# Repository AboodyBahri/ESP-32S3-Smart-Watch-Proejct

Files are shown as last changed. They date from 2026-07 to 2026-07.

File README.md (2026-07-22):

<div align="center">
  <h1>⌚ Tactical Watch Pro (ESP32-S3)</h1>
  <p><b>Senior Graduation Project | Department of Electronics Engineering — University of Tabuk</b></p>
  <p>An end-to-end, full-stack IoT smartwatch ecosystem engineered around the <b>ESP32-S3 SuperMini</b>. Combines embedded C++ firmware, real-time PPG biometric tracking, a 3D-printed parametric enclosure, and a web-based tele-health analytics dashboard.</p>
</div>

<hr />

<h2>📸 System Gallery</h2>

<div align="center">
  <h3>Hardware Prototype & Analytics Dashboard</h3>
</div>

<table width="100%">
  <tr>
    <td align="center" width="50%">
      <h4>Physical Hardware Prototype</h4>
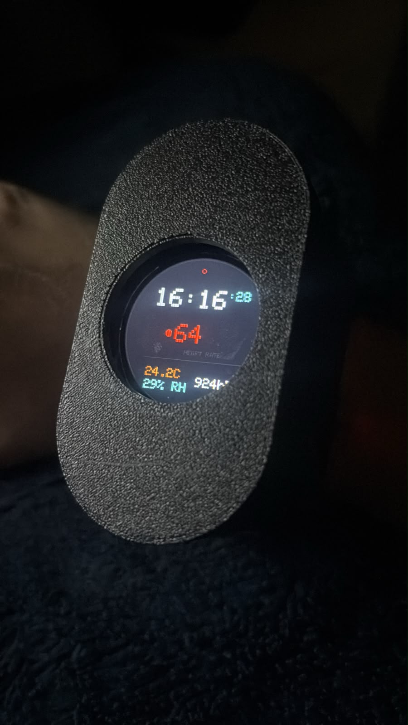
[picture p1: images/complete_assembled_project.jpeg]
Complete Assembled Project
      
    </td>
    <td align="center" width="50%">
      <h4>Web UI Analytics Dashboard</h4>
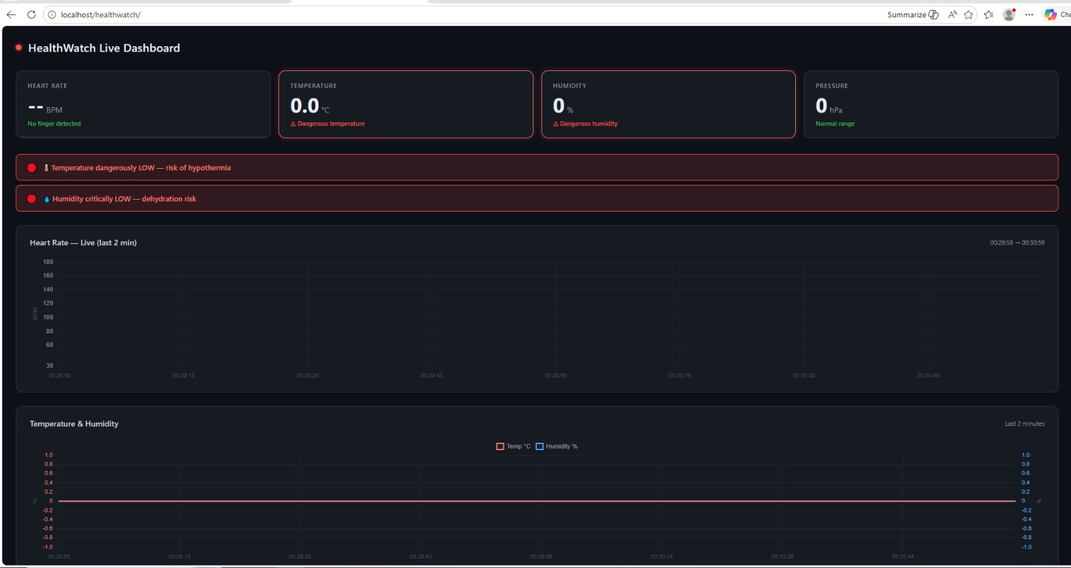
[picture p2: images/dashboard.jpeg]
Watch UI Dashboard
      
    </td>
  </tr>
</table>

<br />

<table width="100%">
  <tr>
    <td align="center" width="50%">
      <h4>Parametric 3D CAD Design</h4>
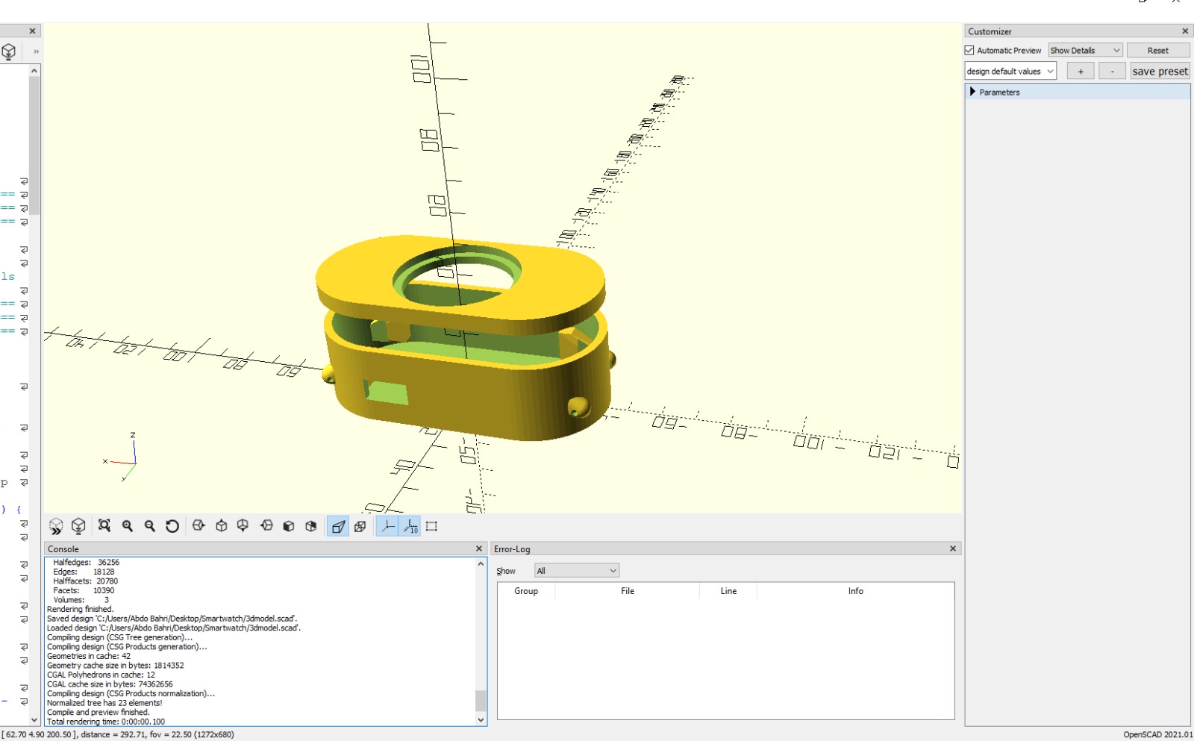
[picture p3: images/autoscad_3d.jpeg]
AutoCAD 3D Model
      
    </td>
    <td align="center" width="50%">
      <h4>Soldered Circuit Assembly</h4>
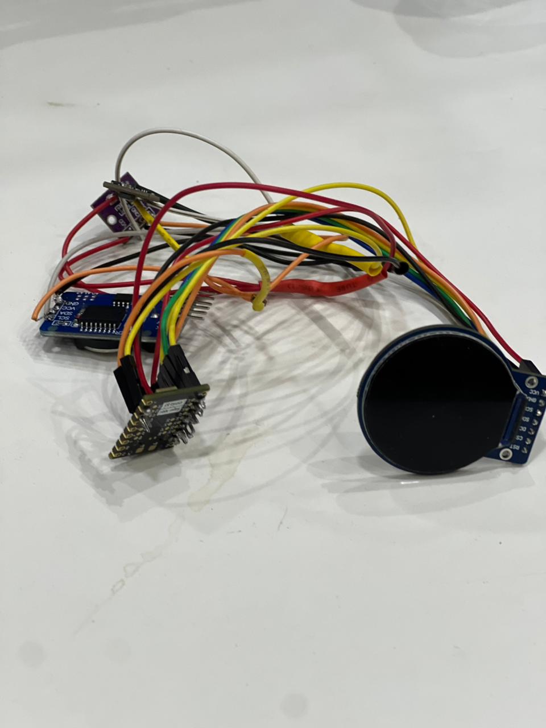
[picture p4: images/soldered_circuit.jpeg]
Soldered Circuit
      
    </td>
  </tr>
  <tr>
    <td align="center" colspan="2">
      <h4>Breadboard Prototype & Signal Testing</h4>
      Test Board Circuit
    </td>
  </tr>
</table>

<hr />

<h2>🛠️ System Architecture & Subsystems</h2>

<table width="100%">
  <thead>
    <tr>
      <th align="left">Subsystem</th>
      <th align="left">Tech / Component</th>
      <th align="left">Engineering Description</th>
    </tr>
  </thead>
  <tbody>
    <tr>
      <td><b>MCU Firmware</b></td>
      <td>ESP32-S3 SuperMini</td>
      <td>Dual-Core Xtensa LX7 @ 240MHz, Wi-Fi 4 &amp; BLE 5.0, Custom C++ Application (<code>esp32s3_code.ino</code>)</td>
    </tr>
    <tr>
      <td><b>Web Dashboard</b></td>
      <td>PHP 8 &amp; JSON Engine</td>
      <td>Hosted tele-health telemetry platform (<code>htdocs/smartwatch/</code>) with RESTful API endpoints for telemetry ingestion</td>
    </tr>
    <tr>
      <td><b>Display UI</b></td>
      <td>GC9A01 LCD (SPI)</td>
      <td>1.28" Round IPS display driven with custom splashscreen header bitmap (<code>splashscreen240.h</code>)</td>
    </tr>
    <tr>
      <td><b>Biometrics</b></td>
      <td>MAX30105 PPG Sensor</td>
      <td>Optical Pulse Oximeter &amp; Heart Rate Sensor operating via I2C interface</td>
    </tr>
    <tr>
      <td><b>Mechanical CAD</b></td>
      <td>OpenSCAD Parametric</td>
      <td>Monolithic 3D capsule enclosure script (<code>smartwatch_full_assembly.scad</code>) with 22mm lug integration</td>
    </tr>
  </tbody>
</table>

<hr />

<h2>🔌 Hardware Pinout Mapping</h2>

<h3>GC9A01 Display Interface (SPI)</h3>
<blockquote>
  <b>Design Note:</b> Display SPI data (MOSI) and reset (RST) lines utilize <b>GPIO 1</b> and <b>GPIO 2</b> to optimize internal physical trace routing away from the USB-C port while minimizing electrical crosstalk with the I2C bus lines.
</blockquote>

<table width="100%">
  <thead>
    <tr>
      <th align="left">GC9A01 Pin</th>
      <th align="left">ESP32-S3 Pin</th>
      <th align="left">Function</th>
      <th align="left">Signal Notes</th>
    </tr>
  </thead>
  <tbody>
    <tr>
      <td><b>SDA (MOSI)</b></td>
      <td><code>GPIO 1</code></td>
      <td>SPI Master Out Slave In</td>
      <td>Custom routed line</td>
    </tr>
    <tr>
      <td><b>RES (RST)</b></td>
      <td><code>GPIO 2</code></td>
      <td>Hardware Reset</td>
      <td>Strapping pin (Boot-safe)</td>
    </tr>
    <tr>
      <td><b>SCL (SCK)</b></td>
      <td><code>GPIO 12</code></td>
      <td>SPI Serial Clock</td>
      <td>Hardware SPI bus</td>
    </tr>
    <tr>
      <td><b>DC</b></td>
      <td><code>GPIO 9</code></td>
      <td>Data / Command Select</td>
      <td>Control line</td>
    </tr>
    <tr>
      <td><b>CS</b></td>
      <td><code>GPIO 13</code></td>
      <td>Chip Select</td>
      <td>Active LOW</td>
    </tr>
    <tr>
      <td><b>VCC / GND</b></td>
      <td><code>3.3V / GND</code></td>
      <td>Power Supply</td>
      <td>Onboard regulated line</td>
    </tr>
  </tbody>
</table>

<br />

<h3>MAX30105 Biometric Sensor (I2C)</h3>

<table width="100%">
  <thead>
    <tr>
      <th align="left">MAX30105 Pin</th>
      <th align="left">ESP32-S3 Pin</th>
      <th align="left">Function</th>
    </tr>
  </thead>
  <tbody>
    <tr>
      <td><b>SDA</b></td>
      <td><code>GPIO 8</code></td>
      <td>I2C Data Line</td>
    </tr>
    <tr>
      <td><b>SCL</b></td>
      <td><code>GPIO 9</code></td>
      <td>I2C Clock Line</td>
    </tr>
    <tr>
      <td><b>VIN / GND</b></td>
      <td><code>3.3V / GND</code></td>
      <td>Power Rails</td>
    </tr>
  </tbody>
</table>

<hr />

<h2>💻 Firmware & Backend API Integration</h2>

<p>The system pairs embedded firmware telemetry with a light server backend for real-time remote monitoring:</p>

<ul>
  <li><b>Microcontroller Firmware:</b> Main application source compiled in <code>esp32s3_code.ino</code>, incorporating precompiled binary assets (<code>FIRMWARE.BIN</code>) and custom UI splash images (<code>splashscreen240.h</code>).</li>
  <li><b>Web API & Dashboard:</b> The <code>htdocs/smartwatch/</code> server stack features an active API worker (<code>api.php</code>) that receives PPG sensor payloads and persists state to <code>data.json</code> for visual display in <code>index.php</code>.</li>
</ul>

<hr />

<h2>📂 Repository Structure</h2>

<pre><code>├── htdocs/
│   └── smartwatch/
│       ├── api.php                         # Telemetry ingestion endpoint
│       ├── data.json                       # Real-time health data storage
│       └── index.php                       # Web tele-health user interface
├── images/                                 # High-resolution documentation photos
│   ├── autoscad_3d.jpeg
│   ├── complete_assembled_project.jpeg
│   ├── dashboard.jpeg
│   ├── soldered_circuit.jpeg
│   └── test_board_circuit
├── esp32s3_code.ino                        # Primary ESP32-S3 Arduino C++ firmware
├── FIRMWARE.BIN                            # Compiled binary distribution file
├── smartwatch_full_assembly.scad           # OpenSCAD 3D printable parametric case script
├── splashscreen240.h                       # Custom 240x240 display splash bitmap array
└── README.md
</code></pre>

<hr />

<h2>🎓 Academic Context</h2>

<table width="100%">
  <tr>
    <td width="25%"><b>Institution</b></td>
    <td><b>University of Tabuk</b></td>
  </tr>
  <tr>
    <td><b>Department</b></td>
    <td>Department of Electronics Engineering</td>
  </tr>
  <tr>
    <td><b>Project Type</b></td>
    <td>Senior Graduation Capstone Project</td>
  </tr>
</table>

<hr />

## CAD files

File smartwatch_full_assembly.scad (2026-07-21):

// ================================================================
// SMARTWATCH PRO — COMPLETE ASSEMBLY
// Original: bottom_case() + top_case()
// NEW:      middle_band() — clips over both assembled halves
// ================================================================
$fn = 120;

// ── Shared dimensions (unchanged from original) ───────────────
wall      = 2.5;
case_h    = 22.0;
case_l    = 70.0;
case_w    = 46.5;
strap_gap = 22.2;

usb_w = 12.0;
usb_h =  5.5;

// ================================================================
// ORIGINAL MODULE 1 — REINFORCED LUGS (unchanged)
// ================================================================
module reinforced_lugs() {
    difference() {
        union() {
            for(y_dir = [-1, 1]) {
                translate([0, y_dir * (strap_gap/2 + 2.5), 0])
                hull() {
                    translate([-4, 0, 0])
                        cube([4, 5, 12], center=true);
                    translate([8, 0, -4])
                        sphere(d=8);
                }
            }
        }
        translate([8, 0, -4])
        rotate([90, 0, 0])
            cylinder(d=2.0, h=case_w + 20, center=true);
        translate([12, 0, 0])
            cube([20, strap_gap, 40], center=true);
    }
}

// ================================================================
// ORIGINAL MODULE 2 — BOTTOM CASE (unchanged)
// ================================================================
module bottom_case() {
    union() {
        difference() {
            hull() {
                translate([-case_l/2+15, 0, 0]) cylinder(d=case_w, h=case_h);
                translate([ case_l/2-15, 0, 0]) cylinder(d=case_w, h=case_h);
            }
            translate([0, 0, wall])
            hull() {
                translate([-case_l/2+15, 0, 0]) cylinder(d=case_w-wall*2, h=case_h);
                translate([ case_l/2-15, 0, 0]) cylinder(d=case_w-wall*2, h=case_h);
            }
            translate([15, case_w/2 - wall - 1, 6])
                cube([usb_w, wall + 5, usb_h], center=true);
            translate([0, 0, -1])
                hull() {
                    cube([16, 16, 0.5], center=true);
                    translate([0,0,wall+2]) cube([12, 12, 0.5], center=true);
                }
            for(i = [-2:2]) {
                translate([-20 + (i*6), -case_w/2 - 2, 10])
                    rotate([45, 0, 0]) cube([1.5, 10, 8]);
            }
        }
        translate([ case_l/2 - 2, 0, case_h/2 + 2]) reinforced_lugs();
        translate([-case_l/2 + 2, 0, case_h/2 + 2]) rotate([0,0,180]) reinforced_lugs();
    }
}

// ================================================================
// ORIGINAL MODULE 3 — TOP CASE / FACEPLATE (unchanged)
// ================================================================
module top_case() {
    difference() {
        hull() {
            translate([-case_l/2+15, 0, 0]) cylinder(d=case_w, h=5);
            translate([ case_l/2-15, 0, 0]) cylinder(d=case_w, h=5);
        }
        translate([0,0,-1]) cylinder(d=33.5, h=10);
        translate([0,0,2.5]) cylinder(d=38.5, h=3.5);
    }
}

// ================================================================
// NEW MODULE — MIDDLE BAND (clip-on, 25mm, open top & bottom)
// ================================================================
// Sits between bottom_case (top rim at z=case_h=22) and
// top_case (bottom rim at z=case_h+band_h=47).
// Snaps over both rims via inward lips. Fully open bore.
// Slide switch cutout: 18mm wide × 5mm tall.
// ================================================================

band_h        = 25.0;   // Exact measured gap

// Snap clip parameters — TUNE IF NEEDED
// If clips are too tight to press on:  raise clip_gap toward 0.5
// If clips feel loose or fall off:     lower clip_gap toward 0.2
clip_gap      = 0.35;   // Clearance between clip lip and case rim
clip_lip      = 1.4;    // How far the lip bites inward over the rim

// Slide switch
sw_w          = 19.0;   // 18mm switch + clearance
sw_h          =  5.5;   // 5mm switch + clearance
sw_x          =  15;    // Lateral offset — same side as USB-C port
                        // Change to 0 to center the switch cutout

// Decorative groove
groove_depth  = 0.55;
groove_w      = 1.1;

// ── Shared hull profile ───────────────────────────────────────
module mhull(h, d_override=0) {
    d = (d_override > 0) ? d_override : case_w;
    hull() {
        translate([-case_l/2+15, 0, 0]) cylinder(d=d, h=h);
        translate([ case_l/2-15, 0, 0]) cylinder(d=d, h=h);
    }
}

module mhull_inner(h, extra=0) {
    // Inner bore = case interior diameter + clip_gap so band slides over
    d = case_w - wall*2 + clip_gap*2 + extra;
    hull() {
        translate([-case_l/2+15, 0, 0]) cylinder(d=d, h=h);
        translate([ case_l/2-15, 0, 0]) cylinder(d=d, h=h);
    }
}

// ── Snap lip ring ─────────────────────────────────────────────
// A washer-shaped ring that bites over a case rim.
// flip=false → clips down over bottom_case top rim (at band z=0)
// flip=true  → clips up   over top_case bottom rim (at band z=band_h)
module snap_lip(flip=false) {
    lip_h = 2.0;   // Height of the retaining lip
    translate([0, 0, flip ? band_h - lip_h : 0])
    difference() {
        mhull(lip_h);                                    // Full outer
        translate([0,0,-0.1])
            mhull_inner(lip_h + 0.2, extra=0);          // Bore with gap
        // Chamfer the leading edge so it guides itself onto the rim
        translate([0, 0, flip ? 0 : lip_h - 0.8])
        difference() {
            mhull(1.0);
            hull() {
                translate([-case_l/2+15, 0, 0])
                    cylinder(d=case_w - clip_lip*2 - 0.4, h=1.0);
                translate([ case_l/2-15, 0, 0])
                    cylinder(d=case_w - clip_lip*2 - 0.4, h=1.0);
            }
        }
    }
}

module middle_band() {
    difference() {
        union() {

            // ── Main shell wall ───────────────────────────────
            difference() {
                mhull(band_h);

                // Open bore — slides over the whole assembly
                translate([0, 0, -1])
                    mhull_inner(band_h + 2);

                // ── Chamfer top rim ───────────────────────────
                translate([0, 0, band_h - 1.0])
                difference() {
                    mhull(1.5);
                    hull() {
                        translate([-case_l/2+15, 0, 0])
                            cylinder(d1=case_w-2.8, d2=case_w+0.2, h=1.5);
                        translate([ case_l/2-15, 0, 0])
                            cylinder(d1=case_w-2.8, d2=case_w+0.2, h=1.5);
                    }
                }

                // ── Chamfer bottom rim ────────────────────────
                translate([0, 0, -0.5])
                difference() {
                    mhull(1.5);
                    hull() {
                        translate([-case_l/2+15, 0, 0])
                            cylinder(d1=case_w+0.2, d2=case_w-2.8, h=1.5);
                        translate([ case_l/2-15, 0, 0])
                            cylinder(d1=case_w+0.2, d2=case_w-2.8, h=1.5);
                    }
                }

                // ── Decorative grooves (1/3 and 2/3 height) ──
                for(gz = [band_h * 0.33, band_h * 0.67]) {
                    translate([0, 0, gz - groove_w/2])
                    difference() {
                        mhull(groove_w);
                        hull() {
                            translate([-case_l/2+15, 0, 0])
                                cylinder(d=case_w - groove_depth*2, h=groove_w);
                            translate([ case_l/2-15, 0, 0])
                                cylinder(d=case_w - groove_depth*2, h=groove_w);
                        }
                    }
                }

                // ── Slide switch cutout ───────────────────────
                // Centered in band height, same face as USB-C
                translate([sw_x, case_w/2 - wall, band_h/2])
                    cube([sw_w, wall + 4, sw_h], center=true);

                // Leading chamfer around switch hole
                translate([sw_x, case_w/2 + 0.5, band_h/2])
                    cube([sw_w + 1.2, 2.0, sw_h + 1.2], center=true);
            }

            // ── Snap lips (added back after bore subtraction) ─
            snap_lip(flip=false);
            snap_lip(flip=true);
        }

        // Final clean bore pass — removes any clip artefacts inside
        translate([0, 0, -2])
            mhull_inner(band_h + 4);
    }
}

// ================================================================
// RENDER — FULL ASSEMBLY
// ================================================================
// Bottom case at z=0
color("DimGray")       bottom_case();

// Middle band sitting right on top of bottom case (z=case_h)
color("SlateGray")
translate([0, 0, case_h]) middle_band();
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

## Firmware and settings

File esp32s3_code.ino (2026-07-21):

#include <WiFi.h>
#include <HTTPClient.h>
#include <Wire.h>
#include <Arduino_GFX_Library.h>
#include <MAX30105.h>
#include <heartRate.h> 
#include <Adafruit_AHTX0.h>
#include <Adafruit_BMP280.h>
#include "RTClib.h"
#include "splashscreen240.h" 

// --- Professional Color Palette ---
#define BLACK       0x0000
#define WHITE       0xFFFF
#define RED         0xF800
#define CYAN        0x07FF
#define DARK_GREY   0x2104
#define ORANGE      0xFD20

// --- Pinout ESP32-S3 SuperMini ---
#define SCK_PIN 12
#define MOSI_PIN 11
#define CS_PIN 13
#define DC_PIN 9
#define RST_PIN 10
#define SDA_PIN 6
#define SCL_PIN 5

Arduino_DataBus *bus = new Arduino_ESP32SPI(DC_PIN, CS_PIN, SCK_PIN, MOSI_PIN);
Arduino_GFX *gfx = new Arduino_GC9A01(bus, RST_PIN, 0, true);

MAX30105 particleSensor;
Adafruit_AHTX0 aht;
Adafruit_BMP280 bmp;
RTC_DS3231 rtc;

const char* ssid     = "project_wifi";
const char* password = "12345678";
String serverUrl     = "http://172.20.10.3/healthwatch/api.php";

const byte RATE_SIZE = 4; 
byte rates[RATE_SIZE];     
byte rateSpot = 0;
long lastBeat = 0;        
int beatAvg = 0;
float cTemp = 0, cHum = 0, cPres = 0;
bool fingerDetected = false;
unsigned long lastPostTime = 0;
unsigned long lastDisplayUpdate = 0;

void setup() {
    Serial.begin(115200);
    gfx->begin();
    gfx->fillScreen(BLACK);

    // Splash screen
    gfx->draw16bitBeRGBBitmap(0, 0, (uint16_t *)splash_gif_data, 240, 240);
    delay(3000); 
    gfx->fillScreen(BLACK);

    Wire.begin(SDA_PIN, SCL_PIN);

    // --- Start WiFi early so it's ready for NTP ---
    WiFi.begin(ssid, password);

    // --- RTC INIT + NTP SYNC ---
    if (!rtc.begin()) {
        Serial.println("ERROR: RTC module not found! Check wiring.");
    } else {
        // Wait up to 8 seconds for WiFi
        unsigned long startAttemptTime = millis();
        while (WiFi.status() != WL_CONNECTED && millis() - startAttemptTime < 8000) {
            delay(500);
            Serial.print(".");
        }

        if (WiFi.status() == WL_CONNECTED) {
            // UTC+3 = Saudi Arabia (Mecca/Riyadh)
            configTime(3 * 3600, 0, "pool.ntp.org", "time.nist.gov");
            struct tm timeinfo;
            if (getLocalTime(&timeinfo, 5000)) {
                rtc.adjust(DateTime(
                    timeinfo.tm_year + 1900,
                    timeinfo.tm_mon + 1,
                    timeinfo.tm_mday,
                    timeinfo.tm_hour,
                    timeinfo.tm_min,
                    timeinfo.tm_sec
                ));
                Serial.println("\n[NTP] RTC synced successfully!");

                // Build dynamic server URL from gateway
                IPAddress gateway = WiFi.gatewayIP();
                serverUrl = "http://" + String(gateway[0]) + "." +
                                        String(gateway[1]) + "." +
                                        String(gateway[2]) + ".3/healthwatch/api.php";
                Serial.print("[WiFi] Server URL: ");
                Serial.println(serverUrl);
            } else {
                Serial.println("\n[NTP] Sync failed — keeping existing RTC time.");
            }
        } else {
            Serial.println("\n[WiFi] Not connected — keeping RTC time.");
            if (rtc.lostPower()) {
                // Last resort fallback if battery died and no WiFi
                rtc.adjust(DateTime(F(__DATE__), F(__TIME__)));
                Serial.println("[RTC] Fallback: set to compile time.");
            }
        }

        // Always confirm current RTC time in Serial
        DateTime now = rtc.now();
        Serial.printf("[RTC] Time: %02d:%02d:%02d  Date: %02d/%02d/%04d\n",
            now.hour(), now.minute(), now.second(),
            now.day(), now.month(), now.year());
    }

    aht.begin();
    if (!bmp.begin(0x76)) bmp.begin(0x77);

    if (particleSensor.begin(Wire, I2C_SPEED_FAST)) {
        particleSensor.setup(); 
        particleSensor.setPulseAmplitudeRed(0x2F); 
        particleSensor.setPulseAmplitudeIR(0x2F);
    }

    drawStaticUI(); 
}

void loop() {
    long irValue = particleSensor.getIR();
    fingerDetected = (irValue > 50000);
    
    if (checkForBeat(irValue) == true) {
        long delta = millis() - lastBeat;
        lastBeat = millis();
        float beatsPerMinute = 60 / (delta / 1000.0);
        if (beatsPerMinute < 220 && beatsPerMinute > 45) {
            rates[rateSpot++] = (byte)beatsPerMinute;
            rateSpot %= RATE_SIZE;
            beatAvg = 0;
            for (byte x = 0; x < RATE_SIZE; x++) beatAvg += rates[x];
            beatAvg /= RATE_SIZE;
        }
    }

    if (millis() - lastDisplayUpdate > 500) { 
        lastDisplayUpdate = millis();
        readSensors();
        updateDisplay();
    }

    if (millis() - lastPostTime > 5000) { 
        lastPostTime = millis();
        sendData();
    }
}

void drawStaticUI() {
    gfx->drawCircle(120, 120, 118, DARK_GREY); 
    gfx->drawFastHLine(40, 160, 160, DARK_GREY); 
    gfx->setTextColor(DARK_GREY);
    gfx->setTextSize(1);
    gfx->setCursor(105, 145);
    gfx->print("HEART RATE");
}

void readSensors() {
    sensors_event_t h, t;
    aht.getEvent(&h, &t);
    cHum = h.relative_humidity;
    float tempReading = bmp.readTemperature();
    cTemp = (isnan(tempReading)) ? t.temperature : tempReading;
    cPres = bmp.readPressure() / 100.0F;
}

void updateDisplay() {
    DateTime now = rtc.now();

    // --- Time ---
    gfx->fillRect(40, 45, 160, 45, BLACK); 
    gfx->setCursor(45, 50);
    gfx->setTextColor(WHITE);
    gfx->setTextSize(4);
    gfx->printf("%02d:%02d", now.hour(), now.minute());
    
    gfx->setTextSize(2);
    gfx->setTextColor(CYAN);
    gfx->printf(":%02d", now.second()); 

    // --- Heart Rate ---
    gfx->fillRect(80, 100, 80, 40, BLACK); 
    if (!fingerDetected) {
        gfx->setTextColor(DARK_GREY);
        gfx->setTextSize(3);
        gfx->setCursor(95, 110);
        gfx->print("---");
    } else {
        gfx->setTextColor(RED);
        gfx->setTextSize(4);
        gfx->setCursor(85, 105);
        gfx->printf("%d", beatAvg);
        int pulseSize = (millis() % 1000 < 500) ? 3 : 5;
        gfx->fillCircle(75, 120, pulseSize, RED);
    }

    // --- Environmental Sensors ---
    gfx->fillRect(30, 170, 180, 45, BLACK);
    gfx->setTextSize(2);
    
    gfx->setTextColor(ORANGE);
    gfx->setCursor(45, 175);
    gfx->printf("%.1fC", cTemp);
    
    gfx->setTextColor(CYAN);
    gfx->setCursor(45, 195);
    gfx->printf("%.0f%% RH", cHum);

    gfx->setTextColor(WHITE);
    gfx->setCursor(130, 185);
    gfx->printf("%.0fhPa", cPres);

    // --- WiFi Status Indicator ---
    if (WiFi.status() == WL_CONNECTED) {
        gfx->fillCircle(120, 20, 3, CYAN);
    } else {
        gfx->drawCircle(120, 20, 3, RED);
    }
}

void sendData() {
    if (WiFi.status() != WL_CONNECTED) {
        WiFi.begin(ssid, password);
        return; 
    }

    HTTPClient http;
    http.begin(serverUrl);
    http.setConnectTimeout(1000);
    http.addHeader("Content-Type", "application/json");
    
    String json = "{\"bpm\":" + String(beatAvg) + 
                  ",\"temp\":" + String(cTemp,1) + 
                  ",\"hum\":" + String(cHum,0) + 
                  ",\"pres\":" + String(cPres,0) + 
                  ",\"finger\":" + (fingerDetected ? "true" : "false") + "}";
    
    int httpResponseCode = http.POST(json);
    http.end();
}

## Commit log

2026-07-21 Rename Test Circuit.jpeg to images/Test Circuit.jpeg
2026-07-21 Rename Test Circuit.jpeg to test_board_circiut
